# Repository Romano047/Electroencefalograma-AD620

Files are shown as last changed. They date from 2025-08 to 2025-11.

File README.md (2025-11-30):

# Prótesis Electroencefalograma AD620
Electroencefalograma-AD620 Realizado en la Escuela de Educación Secundaria Técnica N°5 "2 de Abril" Temperley, Buenos Aires, Argentina. 

Proyecto objetivamente orientado a la investigación y el desarrollo con fines educativos de las señales emitidas por el cerebro e implementarlas en una prótesis de brazo.

Desarrollado por Iván Romano, 7mo 6ta, 2025.

Realizado en "Proyecto y Diseño Electrónico" a cargo del Prof. Martín Leguizamón. 

*PROYECTO ESCOLAR CONCLUIDO.*

Este repositorio será actualizado en caso de investigaciones futuras.

Diseño de Hardware Finalizado y presente en el repositorio. 

# Material y softare utilizados
- Desarrollo de PCB: KiCad 8.0 
- Simulador: MicroCap12
- Amplificadores : AD620an - LM358

# Guía de Repositorio
- Hardwre: Diseño de Módulos PCBs y huellas utilizadas en el proyecto.

  - Fuente_EEG
    - Fuente empleada en el proyecto adaptada al uso de ServoMotores como Output (DESCARTADO).

  - Amplificador_EEG
    - Ampificador Empleado en el proyecto.

  - MicroControlador_EEG: En desarrollo (Versión preeliminar en Alpha) DESCARTADO.

  - Trazado: En esta carpeta se encontrará el trazado empleado para la fabricación manual de las PCBs.

  - Simulación: Esquemático principal del proyecto simulado mediante el software de MicroCap.
 
  - Librerías externas empleadas:
    - E.E.S.T. n°5 , Prof. Mariano Bustos y alumnos del industrial de Temperley.
    - MacroLib , Prof. Maximiliano Andrés Barzola.
    - Logo R , huellas y logos creados por el director de este repositorio.

- 3D: Archivos correspondientes a los diseños 3D del proyecto (Soportes de PCBs).
- Informe: Informe detallado del proyecto, principios de funcionamiento, desarollo y conclusiones obtenidas, Archivo Diagrama de Gantt.
- Manual de Usuario.
- Funcionamiento: Fotos y videos de los resultados prácticos obtenidos. 

# Última Actualización

- Conclusión escolar del proyecto (20 de Nov de 2025).
- Informe final del proyecto.
- Manual de ususario.
- Resultados de funcionamiento.

Cámbios observables en rama "main".

v4.0 - 29 Noviembre 2025

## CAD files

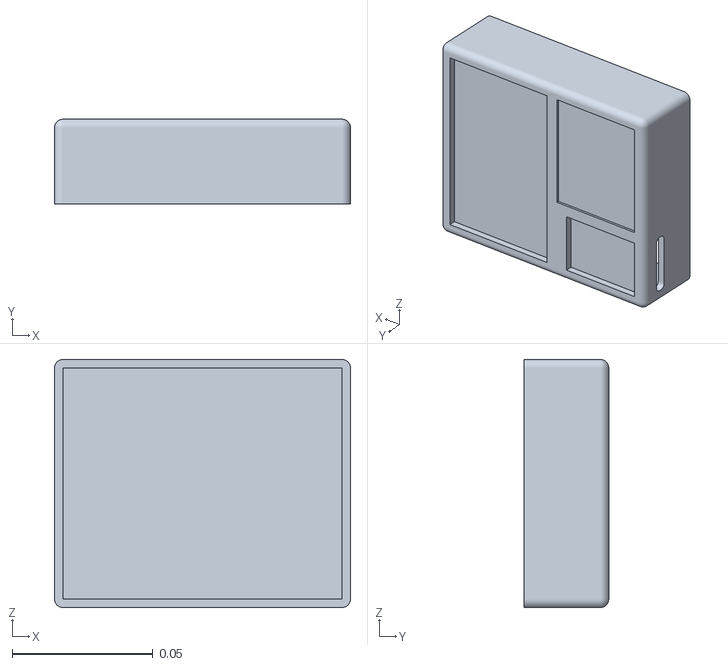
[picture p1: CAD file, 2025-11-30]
3D/Electroencefalógrafo_Soporte.stl
0.105 x 0.03 x 0.088

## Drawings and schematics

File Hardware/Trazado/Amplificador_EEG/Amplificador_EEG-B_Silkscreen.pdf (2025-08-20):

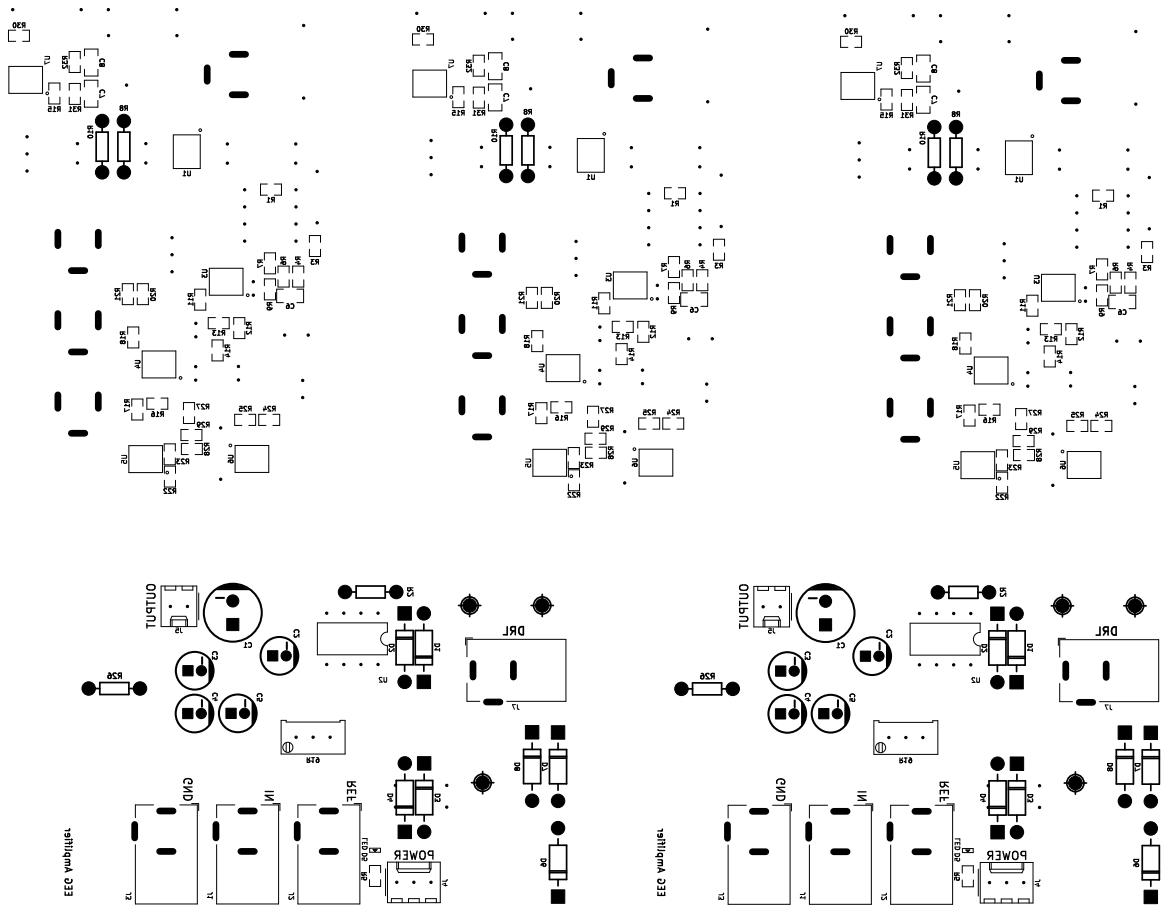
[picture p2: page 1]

C1 J4 POWER J1 IN C2 J2 REF D5 LED D6 D2C3 D8 C5 R2 R19 C4 R5 C7 U6 R3 R12 R32 R13 R6 R10 R18 R27 R28 U7 R17 U3 R21R11 R30 C6 R4 U5 R1 C8 R24 R22 R25 R16 R14 U1 R31 R20 R9 R29 R23

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

EEG Amplifier EEG Amplifier U2 D1

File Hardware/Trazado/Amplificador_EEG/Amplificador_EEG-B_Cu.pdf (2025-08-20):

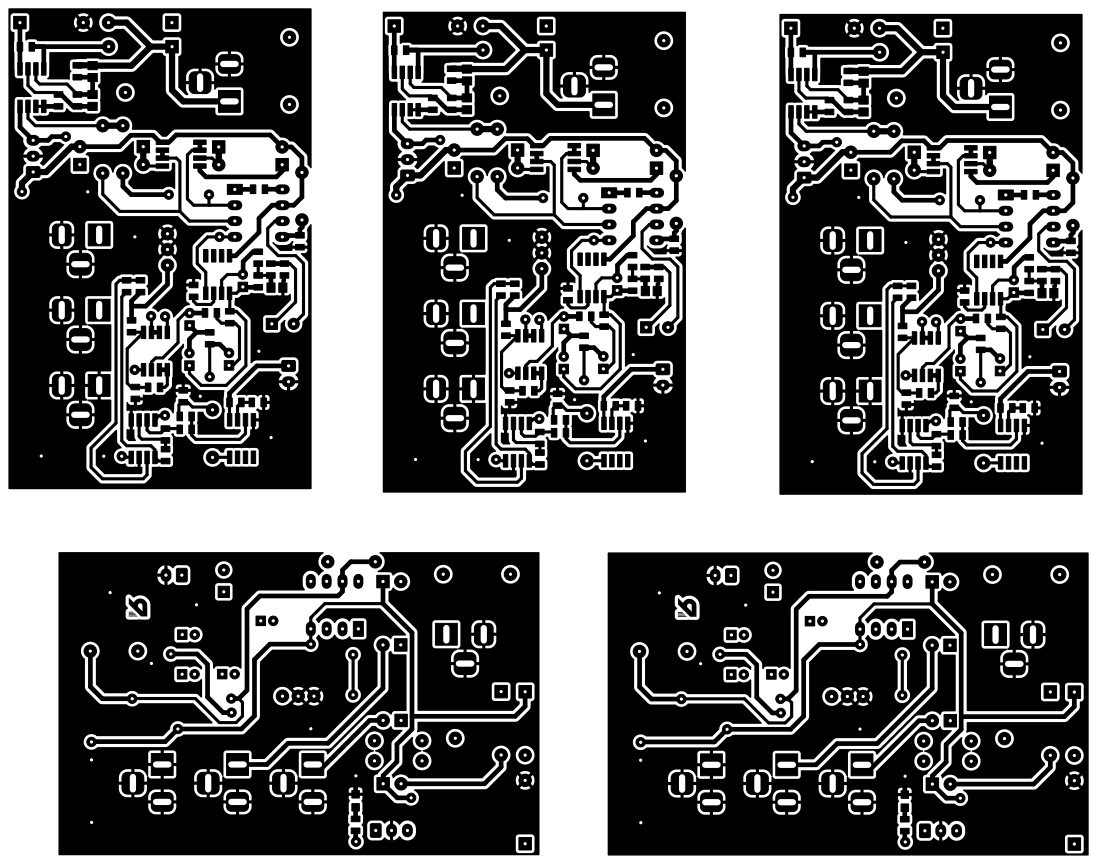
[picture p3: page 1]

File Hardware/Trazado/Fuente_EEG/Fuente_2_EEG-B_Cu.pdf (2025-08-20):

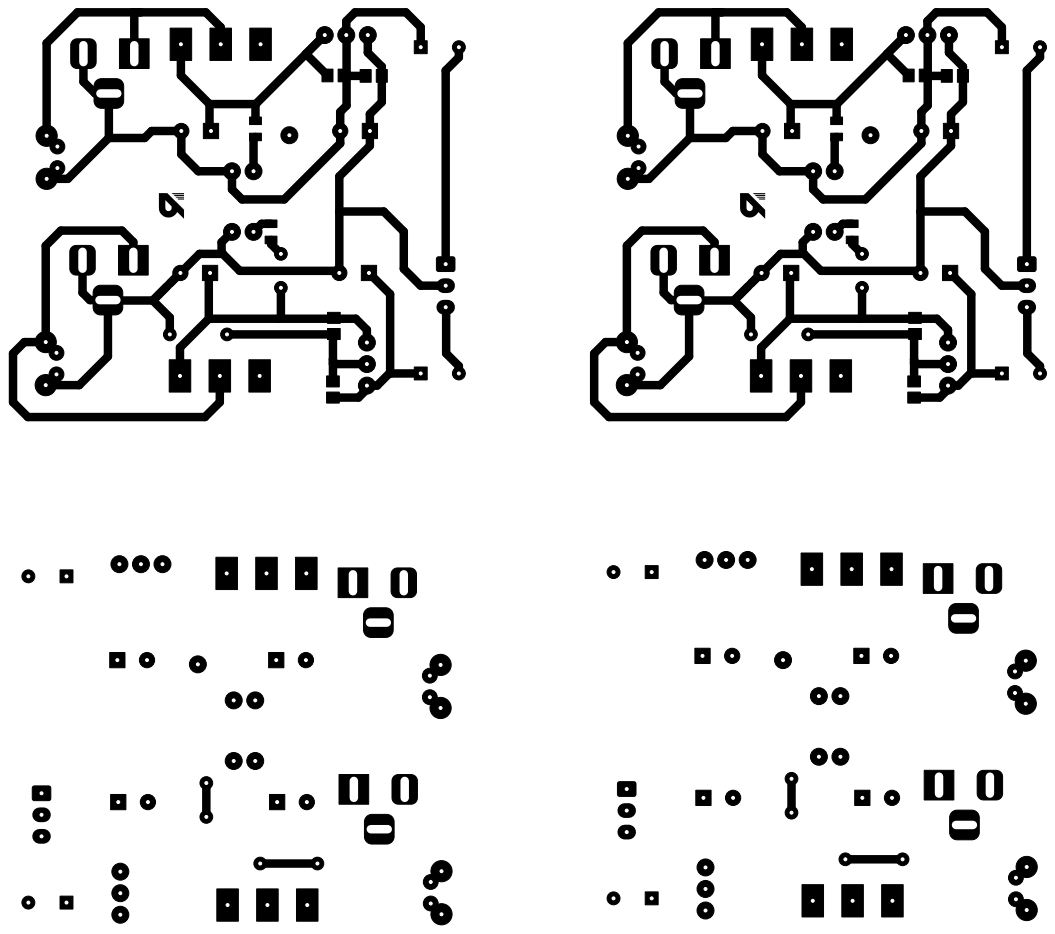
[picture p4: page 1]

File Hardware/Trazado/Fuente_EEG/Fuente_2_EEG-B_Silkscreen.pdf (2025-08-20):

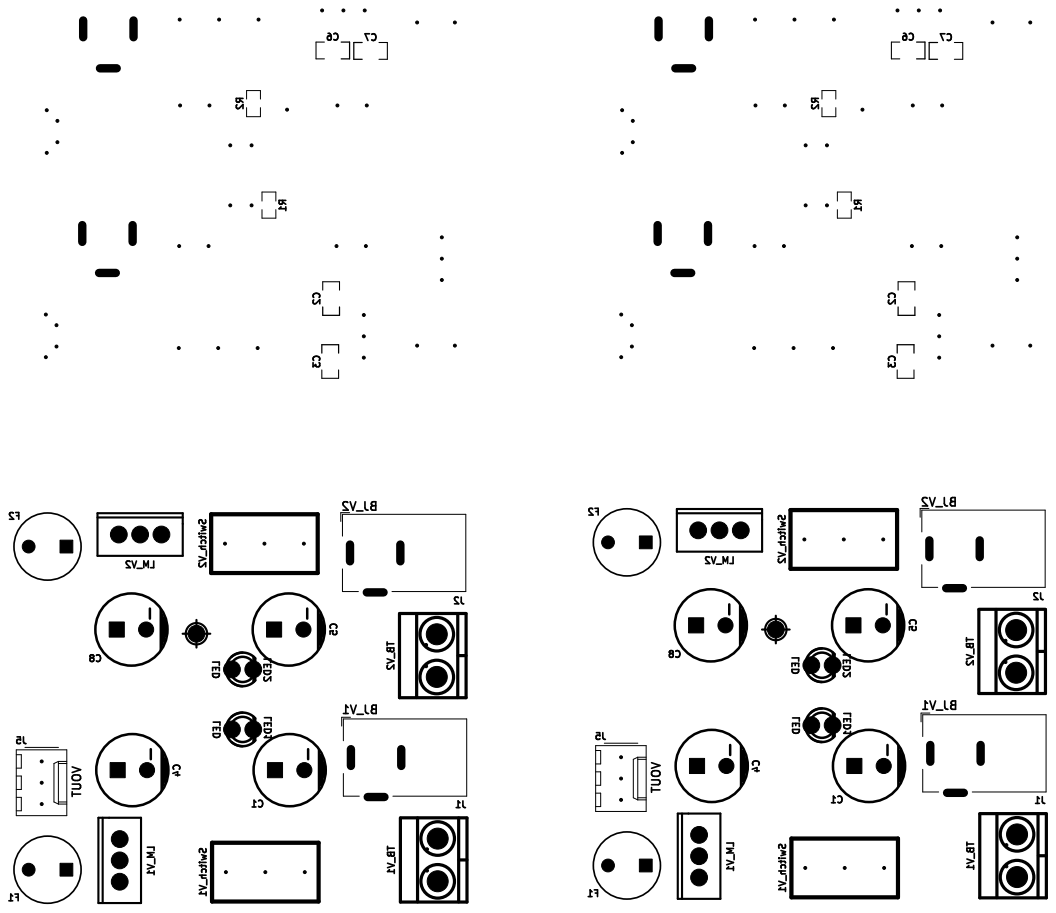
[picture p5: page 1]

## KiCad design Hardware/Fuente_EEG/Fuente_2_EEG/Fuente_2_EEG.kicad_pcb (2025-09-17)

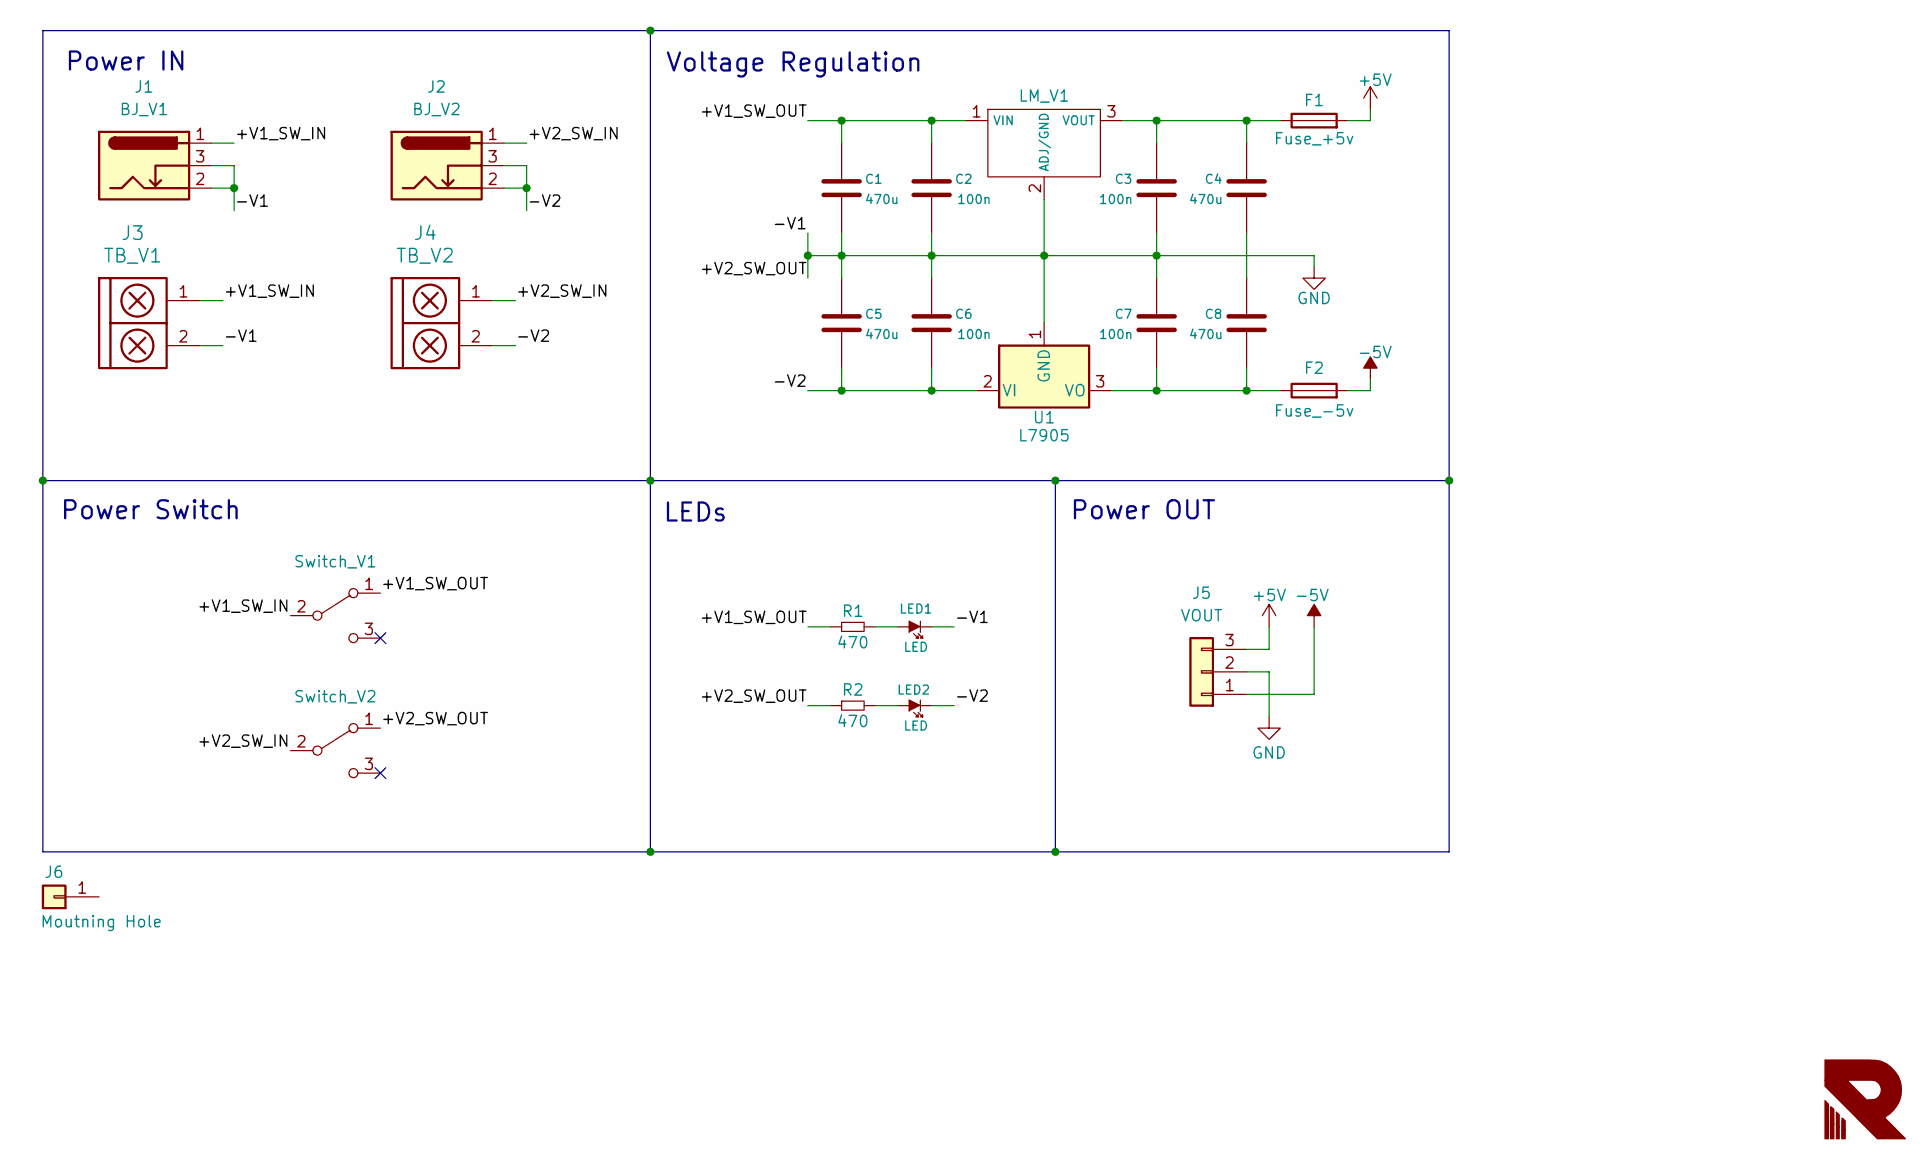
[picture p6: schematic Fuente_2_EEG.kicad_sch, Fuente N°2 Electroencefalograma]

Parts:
C1, C4, C5, C8: 470u; CAP_ELEC_8x11.5mm
C2, C3, C6, C7: 100n; C_0805
F1: Fuse_+5v; Fuse_Cylinder_8mm
F2: Fuse_-5v; Fuse_Cylinder_8mm
J1: BJ_V1; BarrelJack_Horizontal
J2: BJ_V2; BarrelJack_Horizontal
J3: TB_V1; BORNERA2_DUO
J4: TB_V2; BORNERA2_DUO
J5: VOUT; Molex_KK-254_AE-6410-03A_1x03_P2.54mm_Vertical
J6: Moutning Hole; hole_2mm
LED1, LED2: LED; led_3mm_green
LM_V1: TO-220
R1, R2: 470; R_0805
Switch_V1, Switch_V2: SW_SPDT; SW_SPDT_TH_Vertical
U1: L7905; TO-220

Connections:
+5V: F1.2, J5.3
-5V: F2.2, J5.1
/+V1_SW_IN: J1.1, J3.1, Switch_V1.2 (B)
/+V1_SW_OUT: C1.1, C2.1, LM_V1.1 (VIN), R1.1, Switch_V1.1 (A)
/+V2_SW_IN: J2.1, J4.1, Switch_V2.2 (B)
/-V2: C5.2, C6.2, J2.2, J2.3, J4.2, LED2.2 (K), U1.2 (VI)
GND: C1.2, C2.2, C3.2, C5.1, C6.1, C7.1, J1.2, J1.3, J3.2, J5.2, LED1.2 (K), LM_V1.2 (ADJ/GND), R2.1, Switch_V2.1 (A), U1.1 (GND)
unnamed: C4.2, C8.1
unnamed: LED1.1 (A), R1.2
unnamed: LED2.1 (A), R2.2
unnamed: C3.1, C4.1, F1.1, LM_V1.3 (VOUT)
unnamed: C7.2, C8.2, F2.1, U1.3 (VO)

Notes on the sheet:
Power OUT
LEDs
Power IN
Power Switch
Voltage Regulation

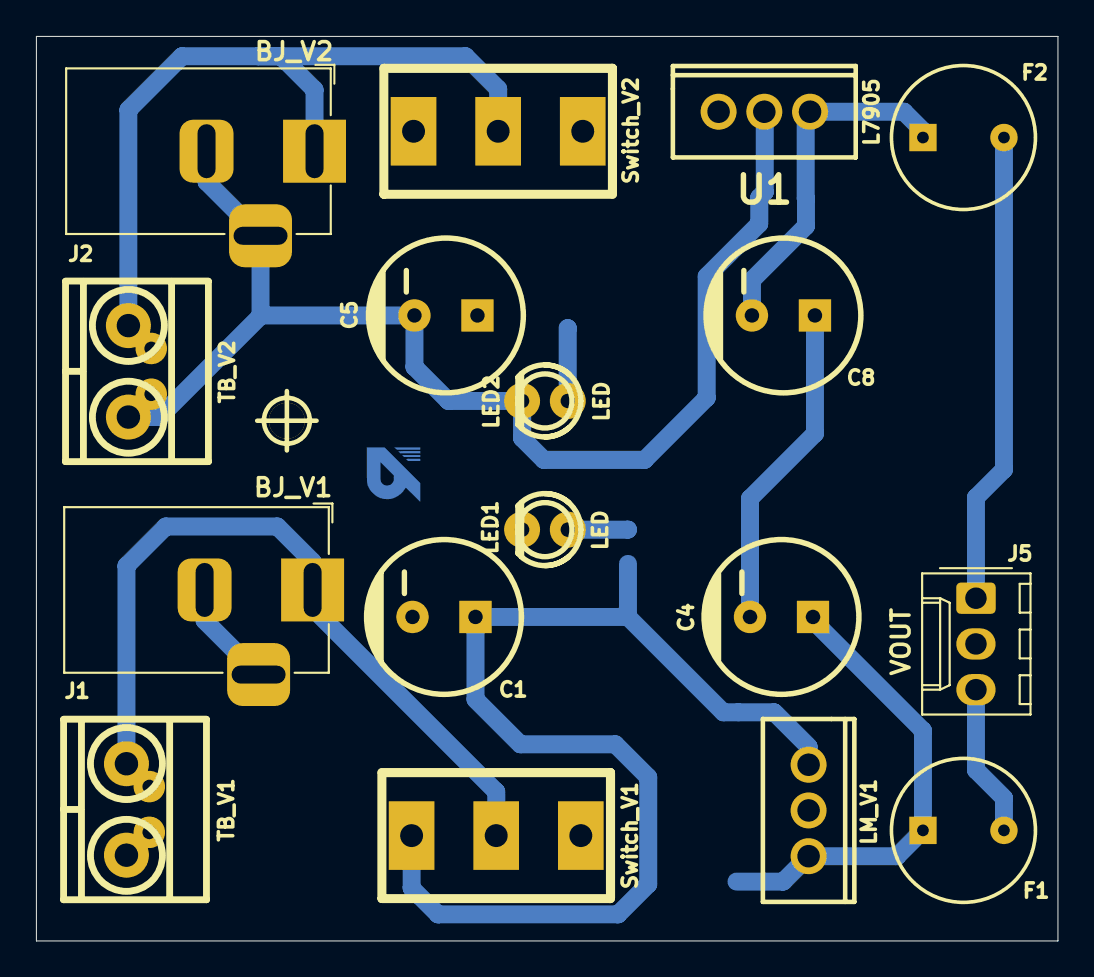
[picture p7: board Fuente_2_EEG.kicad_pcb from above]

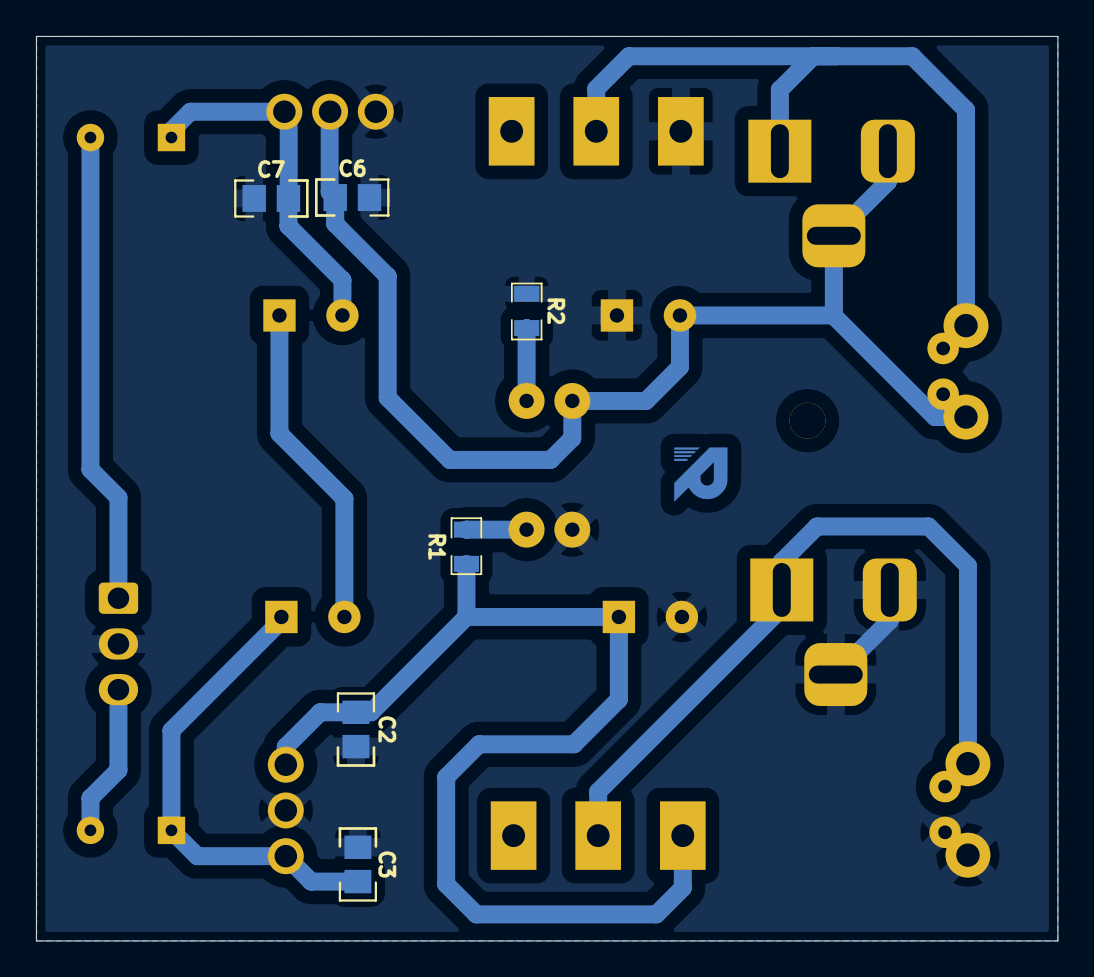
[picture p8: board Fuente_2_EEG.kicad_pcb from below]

Board: 2 copper layers, 56.8 x 50.2 mm, 24 parts (6 on the bottom side), 12 nets.

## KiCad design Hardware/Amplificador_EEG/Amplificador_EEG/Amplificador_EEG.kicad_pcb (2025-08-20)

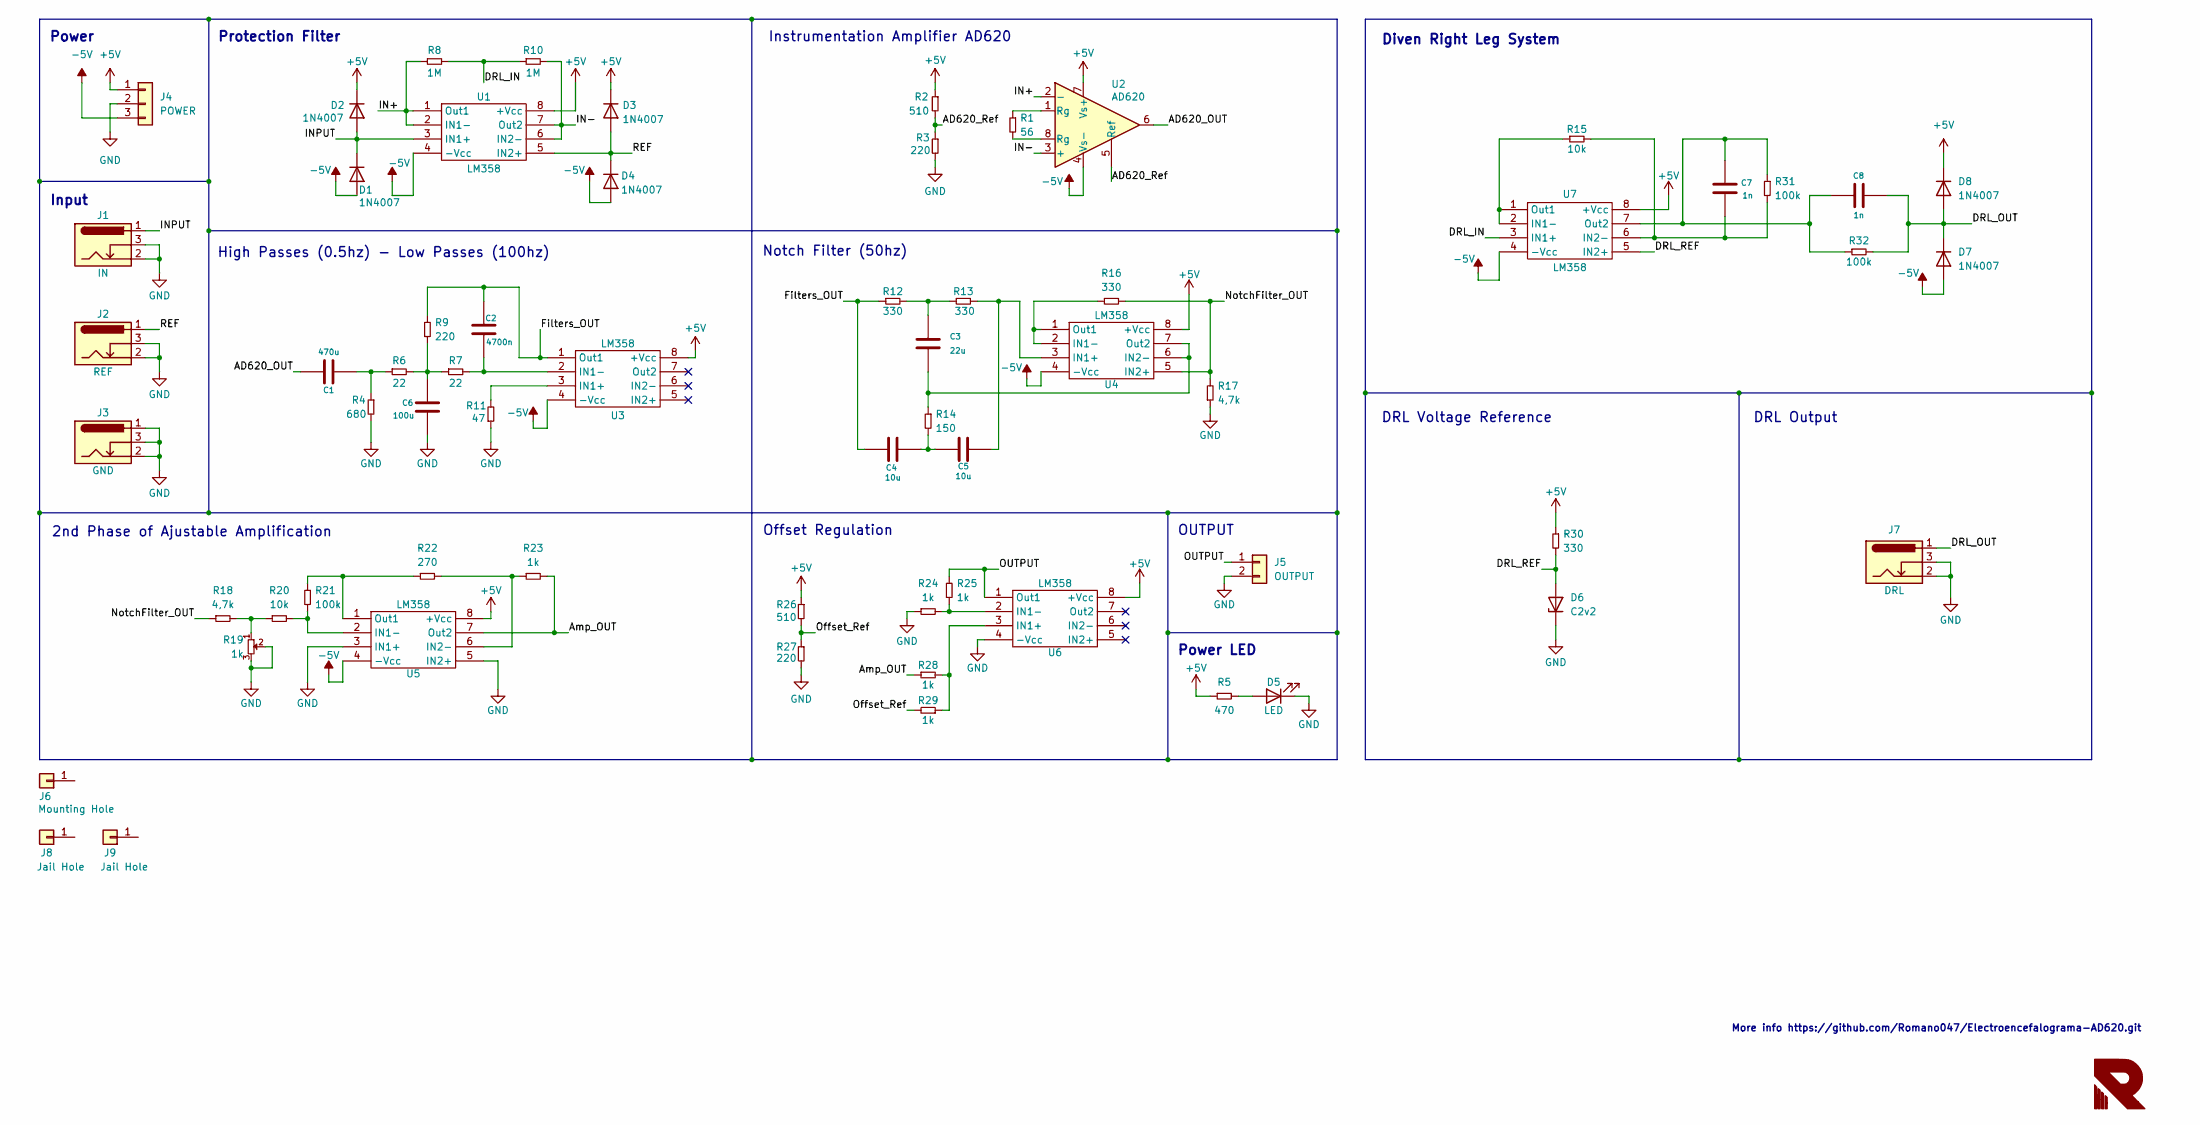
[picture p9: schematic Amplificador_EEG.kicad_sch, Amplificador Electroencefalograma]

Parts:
C1: 470u; CAP_ELEC_8x11.5mm
C2: 4700n; CAP_ELEC_5x11mm
C3: 22u; CAP_ELEC_5x11mm
C4, C5: 10u; CAP_ELEC_5x11mm
C6: 100u; C_0805
C7, C8: 1n; C_0805
D1, D2, D3, D4, D7, D8: 1N4007; DO-41
D5: LED; Led_0805
D6: C2v2; DO-41
J1: IN; BarrelJack_Horizontal
J2: REF; BarrelJack_Horizontal
J3: GND; BarrelJack_Horizontal
J4: POWER; Molex_KK-254_AE-6410-03A_1x03_P2.54mm_Vertical
J5: OUTPUT; Molex_KK-254_AE-6410-02A_1x02_P2.54mm_Vertical
J6: Mounting Hole; hole_2mm
J7: DRL; BarrelJack_Horizontal
J8, J9: Jail Hole; hole_2mm
R1: 56; R_0805
R2, R26: 510; RES0.3
R3, R9, R27: 220; R_0805
R4: 680; R_0805
R5: 470; R_0805
R6, R7: 22; R_0805
R8, R10: 1M; RES0.3
R11: 47; R_0805
R12, R13, R16, R30: 330; R_0805
R14: 150; R_0805
R15, R20: 10k; R_0805
R17, R18: 4,7k; R_0805
R19: 1k; Potenciometer_Trimpot
R21, R31, R32: 100k; R_0805
R22: 270; R_0805
R23, R24, R25, R28, R29: 1k; R_0805
U1, U3, U4, U5, U6, U7: LM358; SSOP-8
U2: AD620; DIP-8

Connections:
+5V: D2.1 (K), D3.1 (K), D8.1 (K), J4.1, R2.1, R5.1, R26.1, R30.1, U1.8 (+Vcc), U2.7 (Vs+), U3.8 (+Vcc), U4.8 (+Vcc), U5.8 (+Vcc), U6.8 (+Vcc), U7.8 (+Vcc)
-5V: D1.2 (A), D4.2 (A), D7.2 (A), J4.3, U1.4 (-Vcc), U2.4 (Vs-), U3.4 (-Vcc), U4.4 (-Vcc), U5.4 (-Vcc), U7.4 (-Vcc)
/AD620_OUT: C1.2, U2.6
/AD620_Ref: R2.2, R3.1, U2.5 (Ref)
/Amp_OUT: R23.2, R28.1, U5.7 (Out2)
/DRL_IN: R8.2, R10.1, U7.3 (IN1+)
/DRL_OUT: C8.2, D7.1 (K), D8.2 (A), J7.1, R32.2
/DRL_REF: D6.2 (A), R30.2, U7.5 (IN2+)
/Filters_OUT: C2.1, C4.1, R9.2, R12.1, U3.1 (Out1)
/IN+: R8.1, U1.1 (Out1), U1.2 (IN1-), U2.2 (-)
/IN-: R10.2, U1.6 (IN2-), U1.7 (Out2), U2.3 (+)
/INPUT: D1.1 (K), D2.2 (A), J1.1, U1.3 (IN1+)
/NotchFilter_OUT: R16.2, R17.2, R18.1, U4.5 (IN2+)
/OUTPUT: J5.1, R25.2, U6.1 (Out1)
/Offset_Ref: R26.2, R27.1, R29.2
/REF: D3.2 (A), D4.1 (K), J2.1, U1.5 (IN2+)
GND: C6.2, D5.1 (K), D6.1 (K), J1.2, J1.3, J2.2, J2.3, J3.1, J3.2, J3.3, J4.2, J5.2, J7.2, J7.3, R3.2, R4.2, R11.1, R17.1, R19.2, R19.3, R24.1, R27.2, U5.3 (IN1+), U5.5 (IN2+), U6.4 (-Vcc)
unnamed: C1.1, R4.1, R6.1
unnamed: C3.1, R12.2, R13.1
unnamed: C4.2, C5.1, R14.2
unnamed: C6.1, R6.2, R7.1, R9.1
unnamed: D5.2 (A), R5.2
unnamed: R1.1, U2.1 (Rg)
unnamed: R1.2, U2.8 (Rg)
unnamed: R18.2, R19.1, R20.1
unnamed: R11.2, U3.3 (IN1+)
unnamed: C2.2, R7.2, U3.2 (IN1-)
unnamed: C5.2, R13.2, U4.3 (IN1+)
unnamed: R16.1, U4.1 (Out1), U4.2 (IN1-)
unnamed: C3.2, R14.1, U4.6 (IN2-), U4.7 (Out2)
unnamed: R20.2, R21.2, U5.2 (IN1-)
unnamed: R22.2, R23.1, U5.6 (IN2-)
unnamed: R21.1, R22.1, U5.1 (Out1)
unnamed: R28.2, R29.1, U6.3 (IN1+)
unnamed: R24.2, R25.1, U6.2 (IN1-)
unnamed: R15.1, U7.1 (Out1), U7.2 (IN1-)
unnamed: C7.2, R15.2, R31.2, U7.6 (IN2-)
unnamed: C7.1, C8.1, R31.1, R32.1, U7.7 (Out2)

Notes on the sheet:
More info https://github.com/Romano047/Electroencefalograma-AD620.git
Offset Regulation
OUTPUT
2nd Phase of Ajustable Amplification
Power LED
High Passes (0.5hz) - Low Passes (100hz)
Instrumentation Amplifier AD620
Diven Right Leg System
Protection Filter
Power
Notch Filter (50hz)
Input
DRL Output
DRL Voltage Reference

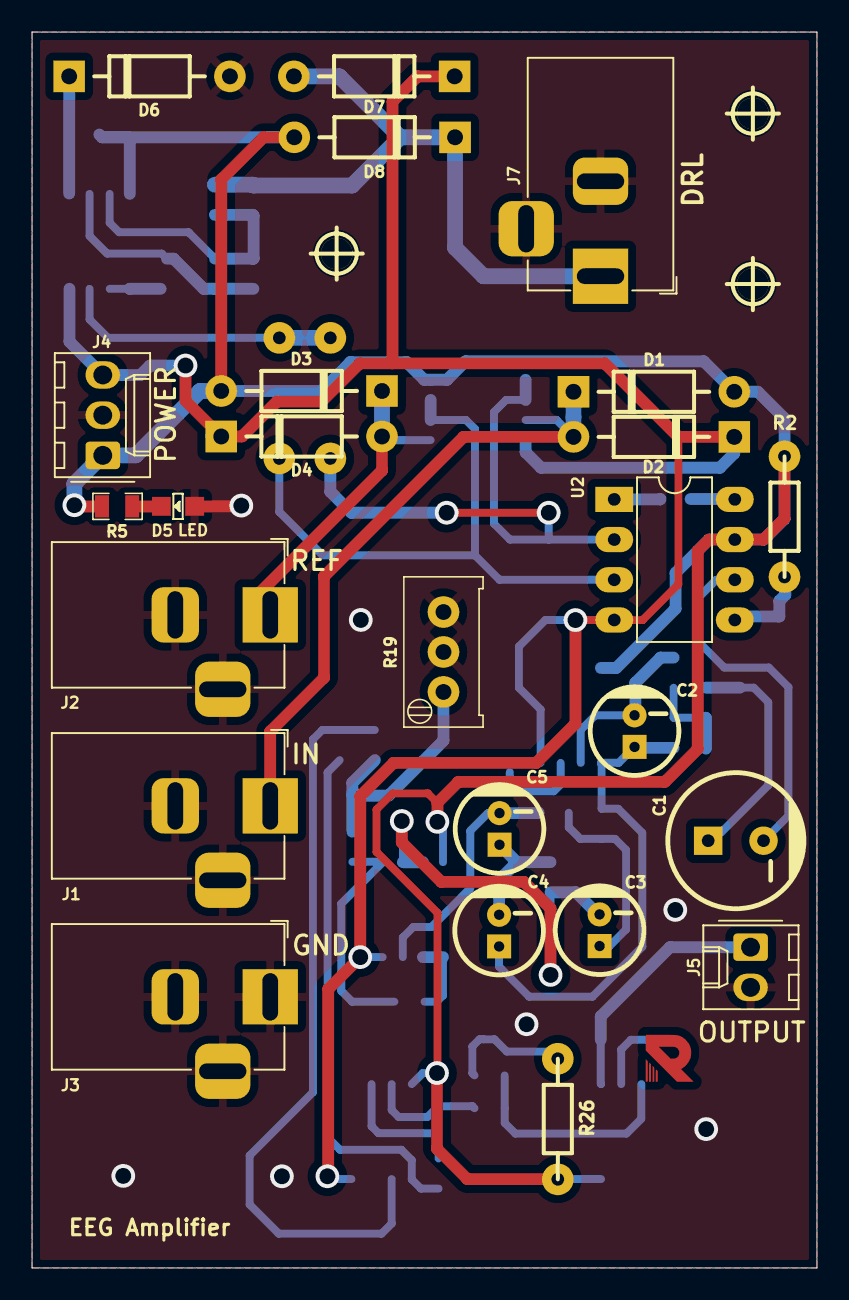
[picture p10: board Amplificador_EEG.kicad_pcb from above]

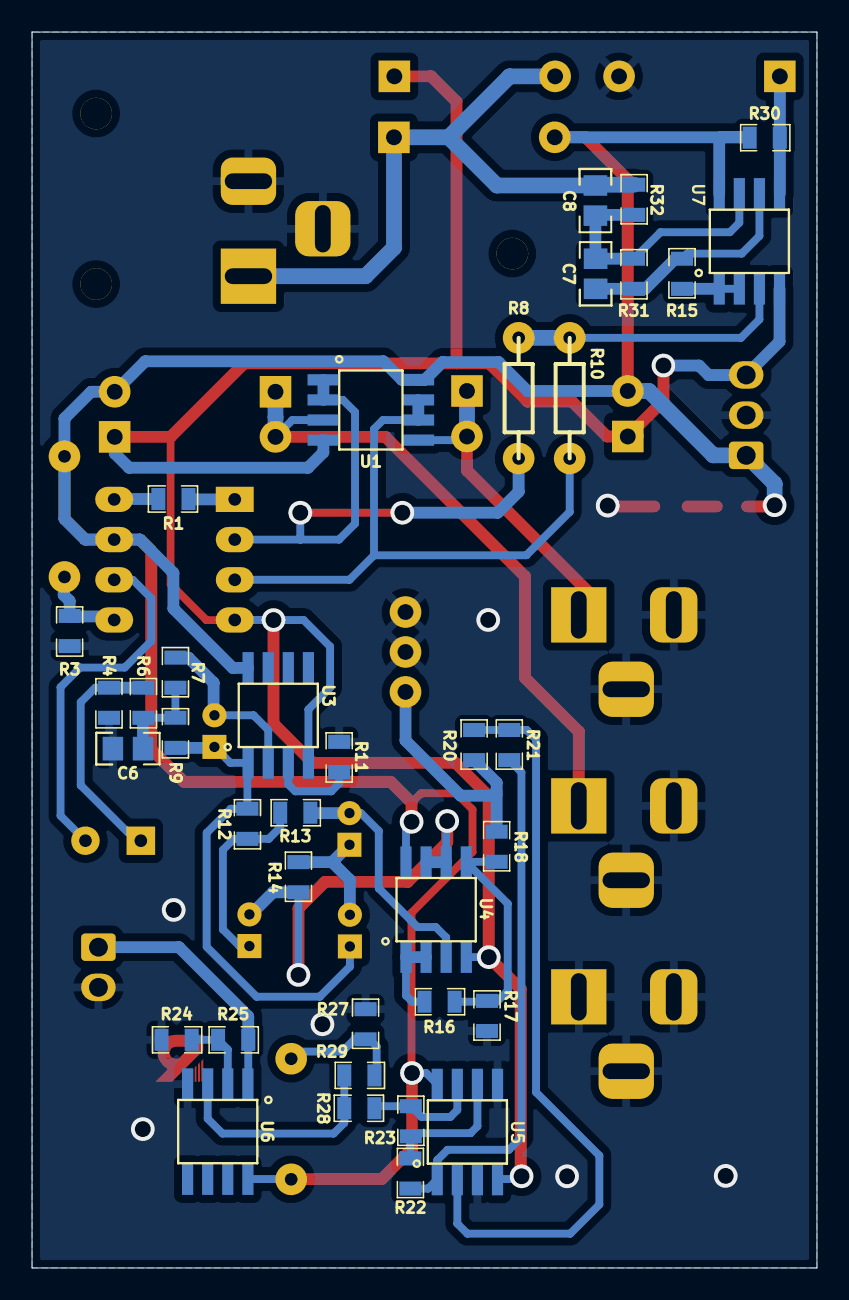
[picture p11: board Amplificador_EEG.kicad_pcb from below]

Board: 2 copper layers, 49.6 x 78.1 mm, 64 parts (37 on the bottom side), 38 nets.

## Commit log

2025-06-21 Última Actualización de Hardware
    [Amplificador_EEG.kicad_pcb, Amplificador_EEG.kicad_sch, Fuente_EEG.kicad_pcb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]
2025-06-23 Actualización Componentes PCBs
    [Amplificador_EEG.kicad_pcb, Amplificador_EEG.kicad_sch, Fuente_EEG.kicad_pcb]
2025-06-27 main Hardware update
    [Amplificador_EEG.kicad_pcb, Amplificador_EEG_Master.kicad_pcb, Amplificador_EEG_Master.kicad_sch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]
2025-07-10 Actualización Amplificador
    [Amplificador_EEG.kicad_pcb, Amplificador_EEG.kicad_sch]
2025-07-10 Actualización de Dimensiones
    [Amplificador_EEG.kicad_pcb]
2025-08-20 PCBs Update
    [Amplificador_EEG.kicad_pcb, Amplificador_EEG.kicad_sch, Fuente_2_EEG.kicad_pcb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]
2025-09-17 Fuente Update
    [Fuente_2_EEG.kicad_pcb, Fuente_2_EEG.kicad_sch]
